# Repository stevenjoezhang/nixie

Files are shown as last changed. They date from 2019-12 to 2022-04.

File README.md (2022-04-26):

# Nixie

## Hardware

- [Arduino Mega 2560](https://store.arduino.cc/products/arduino-mega-2560-rev3)
- [IN-14 Nixie tube](https://en.wikipedia.org/wiki/Nixie_tube)
- [DS3231](https://www.maximintegrated.com/en/products/analog/real-time-clocks/DS3231.html)

## Software Dependencies

- [Rtc](https://github.com/Makuna/Rtc)
- [SoftwareWire](https://github.com/Testato/SoftwareWire)

## Related Work

- [NixieTubeClock](https://github.com/zer0pwned/NixieTubeClock)

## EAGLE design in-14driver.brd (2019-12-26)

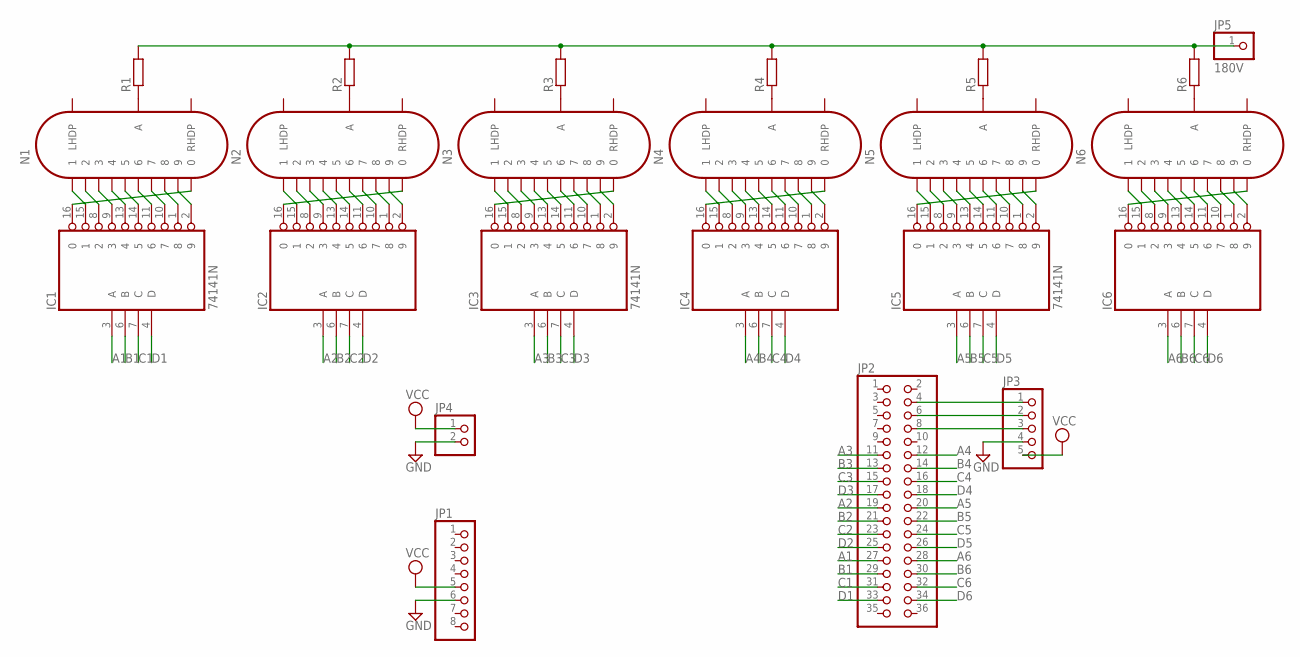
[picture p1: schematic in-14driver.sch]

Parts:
IC1, IC2, IC3, IC4, IC5, IC6: 74141N; DIL16
JP1: PINHD-1X8; 1X08
JP2: PINHD-2X18; 2X18
JP3: PINHD-1X5; 1X05
JP4: PINHD-1X2; 1X02
JP5: 180V; 1X01
N1, N2, N3, N4, N5, N6: IN-14
R1, R2, R3, R4, R5, R6: R-EU_0207/10; 0207/10

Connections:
A1: IC1.3 (A), JP2.27
A2: IC2.3 (A), JP2.19
A3: IC3.3 (A), JP2.11
A4: IC4.3 (A), JP2.12
A5: IC5.3 (A), JP2.20
A6: IC6.3 (A), JP2.28
B1: IC1.6 (B), JP2.29
B2: IC2.6 (B), JP2.21
B3: IC3.6 (B), JP2.13
B4: IC4.6 (B), JP2.14
B5: IC5.6 (B), JP2.22
B6: IC6.6 (B), JP2.30
C1: IC1.7 (C), JP2.31
C2: IC2.7 (C), JP2.23
C3: IC3.7 (C), JP2.15
C4: IC4.7 (C), JP2.16
C5: IC5.7 (C), JP2.24
C6: IC6.7 (C), JP2.32
D1: IC1.4 (D), JP2.33
D2: IC2.4 (D), JP2.25
D3: IC3.4 (D), JP2.17
D4: IC4.4 (D), JP2.18
D5: IC5.4 (D), JP2.26
D6: IC6.4 (D), JP2.34
GND: IC1.12 (GND), IC2.12 (GND), IC3.12 (GND), IC4.12 (GND), IC5.12 (GND), IC6.12 (GND), JP1.6, JP3.4, JP4.2
unnamed: IC2.15 (1), N2.0 (1)
unnamed: IC2.8 (2), N2.9 (2)
unnamed: IC2.9 (3), N2.8 (3)
unnamed: IC2.13 (4), N2.7 (4)
unnamed: IC2.14 (5), N2.6 (5)
unnamed: IC2.11 (6), N2.5 (6)
unnamed: IC2.10 (7), N2.4 (7)
unnamed: IC2.1 (8), N2.3 (8)
unnamed: IC2.2 (9), N2.2 (9)
unnamed: IC2.16 (0), N2.1 (0)
unnamed: N2.A, R2.1
unnamed: IC3.15 (1), N3.0 (1)
unnamed: IC3.8 (2), N3.9 (2)
unnamed: IC3.9 (3), N3.8 (3)
unnamed: IC3.13 (4), N3.7 (4)
unnamed: IC3.14 (5), N3.6 (5)
unnamed: IC3.11 (6), N3.5 (6)
unnamed: IC3.10 (7), N3.4 (7)
unnamed: IC3.1 (8), N3.3 (8)
unnamed: IC3.2 (9), N3.2 (9)
unnamed: JP2.4, JP3.1
unnamed: JP2.6, JP3.2
unnamed: JP2.8, JP3.3
unnamed: IC3.16 (0), N3.1 (0)
unnamed: N3.A, R3.1
unnamed: IC4.15 (1), N4.0 (1)
unnamed: IC4.8 (2), N4.9 (2)
unnamed: IC4.9 (3), N4.8 (3)
unnamed: IC4.13 (4), N4.7 (4)
unnamed: IC4.14 (5), N4.6 (5)
unnamed: IC4.11 (6), N4.5 (6)
unnamed: IC4.10 (7), N4.4 (7)
unnamed: IC4.1 (8), N4.3 (8)
unnamed: IC4.2 (9), N4.2 (9)
unnamed: IC4.16 (0), N4.1 (0)
unnamed: N4.A, R4.1
unnamed: IC5.15 (1), N5.0 (1)
unnamed: IC5.8 (2), N5.9 (2)
unnamed: IC5.9 (3), N5.8 (3)
unnamed: IC5.13 (4), N5.7 (4)
unnamed: IC5.14 (5), N5.6 (5)
unnamed: IC5.11 (6), N5.5 (6)
unnamed: IC5.10 (7), N5.4 (7)
unnamed: IC1.15 (1), N1.0 (1)
unnamed: IC1.8 (2), N1.9 (2)
unnamed: IC1.9 (3), N1.8 (3)
unnamed: IC1.13 (4), N1.7 (4)
unnamed: IC1.14 (5), N1.6 (5)
unnamed: IC1.11 (6), N1.5 (6)
unnamed: IC1.10 (7), N1.4 (7)
unnamed: IC1.1 (8), N1.3 (8)
unnamed: IC1.2 (9), N1.2 (9)
unnamed: IC1.16 (0), N1.1 (0)
unnamed: IC5.1 (8), N5.3 (8)
unnamed: IC5.2 (9), N5.2 (9)
unnamed: IC5.16 (0), N5.1 (0)
unnamed: N5.A, R5.1
unnamed: IC6.15 (1), N6.0 (1)
unnamed: IC6.8 (2), N6.9 (2)
unnamed: IC6.9 (3), N6.8 (3)
unnamed: IC6.13 (4), N6.7 (4)
unnamed: IC6.14 (5), N6.6 (5)
unnamed: IC6.11 (6), N6.5 (6)
unnamed: N1.A, R1.1
unnamed: IC6.10 (7), N6.4 (7)
unnamed: IC6.1 (8), N6.3 (8)
unnamed: IC6.2 (9), N6.2 (9)
unnamed: IC6.16 (0), N6.1 (0)
unnamed: N6.A, R6.1
VCC: IC1.5 (VCC), IC2.5 (VCC), IC3.5 (VCC), IC4.5 (VCC), IC5.5 (VCC), IC6.5 (VCC), JP1.5, JP3.5, JP4.1
VH: JP5.1, R1.2, R2.2, R3.2, R4.2, R5.2, R6.2

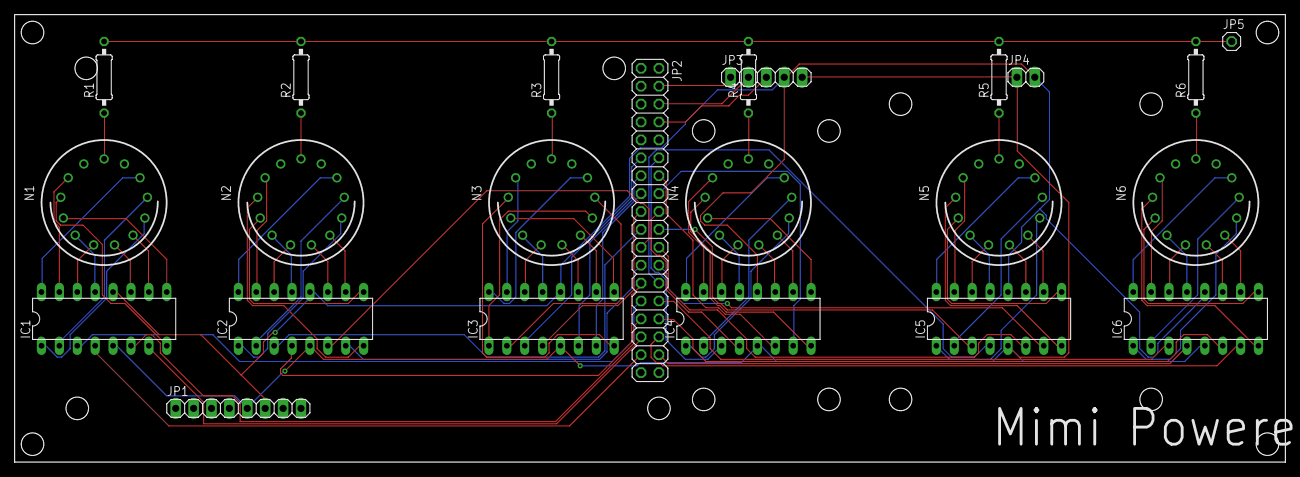
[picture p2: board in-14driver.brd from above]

Board: 2 copper layers, 180.3 x 63.5 mm, 23 parts (0 on the bottom side), 96 nets.

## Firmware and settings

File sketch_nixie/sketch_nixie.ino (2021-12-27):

#define SDA 25
#define SCL 23
#define VCC 27
#define STEPS 18

#include <SoftwareWire.h>  // must be included here so that Arduino library object file references work
#include <RtcDS3231.h>

SoftwareWire myWire(SDA, SCL);
RtcDS3231<SoftwareWire> Rtc(myWire);

int pins[][4] = {{46, 48, 50, 52}, {38, 40, 42, 44}, {30, 32, 34, 36}, {31, 33, 35, 37}, {39, 41, 43, 45}, {47, 49, 51, 53}};
unsigned int state[6] = {0, 0, 0, 0, 0, 0};
int counter = 0;

void setup() {
  // put your setup code here, to run once:
  pinMode(LED_BUILTIN, OUTPUT);
  digitalWrite(LED_BUILTIN, LOW);
  pinMode(VCC, OUTPUT);
  digitalWrite(VCC, HIGH);
  for (int i = 0; i < 6; i++) {
    for (int j = 0; j < 4; j++) {
      pinMode(pins[i][j], OUTPUT);
    }
  }
  Serial.begin(115200);

  Serial.print("compiled: ");
  Serial.print(__DATE__);
  Serial.println(__TIME__);

  Rtc.Begin();

  RtcDateTime compiled = RtcDateTime(__DATE__, __TIME__);
  printDateTime(compiled);
  Serial.println();

  if (!Rtc.IsDateTimeValid()) {
    if (Rtc.LastError() != 0) {
      // we have a communications error
      // see https://www.arduino.cc/en/Reference/WireEndTransmission for
      // what the number means
      Serial.print("RTC communications error = ");
      Serial.println(Rtc.LastError());
    } else {
      // Common Causes:
      //    1) first time you ran and the device wasn't running yet
      //    2) the battery on the device is low or even missing

      Serial.println("RTC lost confidence in the DateTime!");

      // following line sets the RTC to the date & time this sketch was compiled
      // it will also reset the valid flag internally unless the Rtc device is
      // having an issue

      Rtc.SetDateTime(compiled);
    }
  }

  if (!Rtc.GetIsRunning()) {
    Serial.println("RTC was not actively running, starting now");
    Rtc.SetIsRunning(true);
  }

  RtcDateTime now = Rtc.GetDateTime();
  if (now < compiled) {
    Serial.println("RTC is older than compile time!  (Updating DateTime)");
    Rtc.SetDateTime(compiled);
  }
  else if (now > compiled) {
    Serial.println("RTC is newer than compile time. (this is expected)");
  }
  else if (now == compiled) {
    Serial.println("RTC is the same as compile time! (not expected but all is fine)");
  }

  // never assume the Rtc was last configured by you, so
  // just clear them to your needed state
  Rtc.Enable32kHzPin(false);
  Rtc.SetSquareWavePin(DS3231SquareWavePin_ModeNone);

  post(state);
}

void loop() {
  // put your main code here, to run repeatedly:
  delay(100);
  RtcDateTime now = Rtc.GetDateTime();
  counter++;
  if (counter == 20) {
    counter = 0;
    printDateTime(now);
    Serial.println();

    if (!now.IsValid()) {
      // Common Causes:
      //  1) the battery on the device is low or even missing and the power line was disconnected
      Serial.println("RTC lost confidence in the DateTime!");
    }
  }
  unsigned int hour = now.Hour();
  unsigned int minute = now.Minute();
  unsigned int second = now.Second();
  if (state[5] == second % 10) return;
  unsigned int newstate[] = {hour / 10, hour % 10, minute / 10, minute % 10, second / 10, second % 10};
  crossFade(state, newstate);
}

void printDateTime(const RtcDateTime& dt) {
  char datestring[20];

  snprintf_P(
    datestring,
    sizeof(datestring) / sizeof(datestring[0]),
    PSTR("%02u/%02u/%04u %02u:%02u:%02u"),
    dt.Month(),
    dt.Day(),
    dt.Year(),
    dt.Hour(),
    dt.Minute(),
    dt.Second()
  );
  Serial.print(datestring);
}

void nixieDisplay(int index, int num) {
  digitalWrite(pins[index][0], num >> 0 & 0b01 ? HIGH : LOW); // A
  digitalWrite(pins[index][1], num >> 1 & 0b01 ? HIGH : LOW); // B
  digitalWrite(pins[index][2], num >> 2 & 0b01 ? HIGH : LOW); // C
  digitalWrite(pins[index][3], num >> 3 & 0b01 ? HIGH : LOW); // D
}

void crossFade(unsigned int* state, unsigned int* newstate) {
  for (int timer = 0; timer <= STEPS; timer++) {
    for (int index = 0; index < 6; index++) {
      nixieDisplay(index, state[index]);
    }
    delay(STEPS - timer);
    for (int index = 0; index < 6; index++) {
      nixieDisplay(index, newstate[index]);
    }
    delay(timer);
  }
  for (int index = 0; index < 6; index++) {
    state[index] = newstate[index];
  }
}

void post(unsigned int* state) {
  for (int num = 1; num < 10; num++) {
    unsigned int newstate[6] = {num, num, num, num, num, num};
    crossFade(state, newstate);
    delay(500);
  }
}
